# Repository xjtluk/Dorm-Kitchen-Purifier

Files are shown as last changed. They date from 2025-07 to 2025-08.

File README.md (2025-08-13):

# Smart Indoor Air Quality Monitor & Purifier

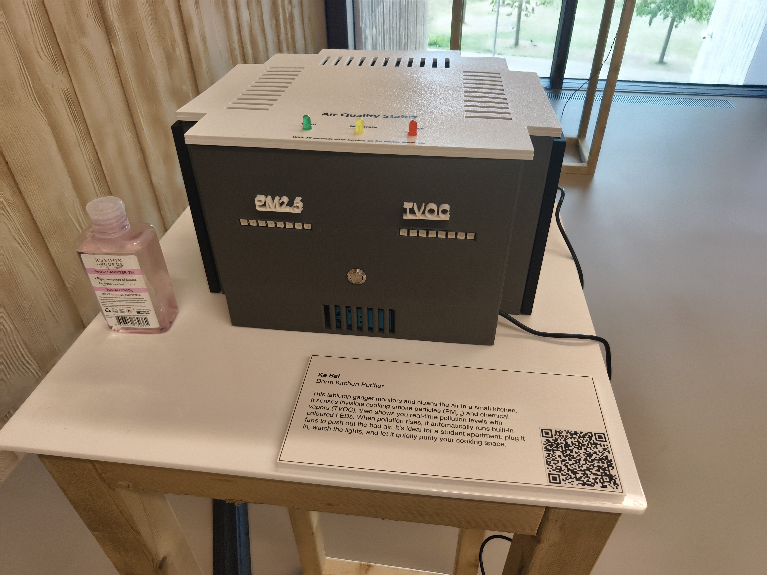
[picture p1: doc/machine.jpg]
机器图片

 
A comprehensive IoT-based air purification and monitoring system designed specifically for student residences, combining real-time pollution detection, automated purification control, and cloud data logging.






## 🌟 Features

- **Real-time Air Quality Monitoring**: Continuous measurement of PM₂.₅ and TVOC levels
- **Automated Purification Control**: Three-tier fan system with intelligent response scaling
- **Visual Feedback System**: Dual LED strips providing immediate air quality status
- **IoT Cloud Integration**: Automatic data logging to ThingSpeak platform
- **Compact Design**: Optimized for 12-15 m² student living spaces
- **Educational Focus**: Open-source design for learning and research

## 📊 Performance Results

### Purification Effectiveness
- **PM₂.₅ Reduction**: 31% reduction in peak concentrations
- **TVOC Reduction**: 13% reduction during active purification
- **Response Time**: System activation within 6 seconds of threshold violation

### System Specifications
- **Detection Range**: PM₂.₅ (0-1000 µg/m³), TVOC (0-60,000 ppb)
- **Sampling Rate**: 2-second intervals for real-time response
- **Clean Air Delivery Rate**: Up to 105 CFM with three-fan configuration
- **Operational Reliability**: 97.3% cloud upload success rate over 720+ hours

## 🔧 Hardware Components

### Core Components
- **Microcontroller**: ESP32 (dual-core, WiFi-enabled)
- **PM₂.₅ Sensor**: PMS5003 (Plantower) - laser-based optical sensing
- **TVOC Sensor**: SGP30 (Sensirion) - metal-oxide semiconductor
- **Purification**: 3x centrifugal fans with HEPA + activated carbon filtration
- **User Interface**: Dual 8-pixel NeoPixel LED strips, tactile control button

### Power & Control
- **Fan Control**: MOSFET-based switching (FQP30N06L N-channel)
- **Power Consumption**: 15W during active purification
- **Communication**: UART (PMS5003), I²C (SGP30), WiFi (cloud logging)

## 📦 Installation

### Hardware Setup
1. **3D Print Enclosure**: Use provided Fusion 360 files (3D model) for compact desktop unit
2. **Circuit Assembly**: Follow schematic for sensor and fan connections
3. **Filter Installation**: Insert HEPA + activated carbon cartridge

```
Pin Connections:
├── PMS5003: UART (pins 16/17)
├── SGP30: I²C (pins 21/22)
├── Fans: Digital control (pins 18/19)
├── NeoPixel LEDs: pins 25/26
└── Control Button: pin 4
```
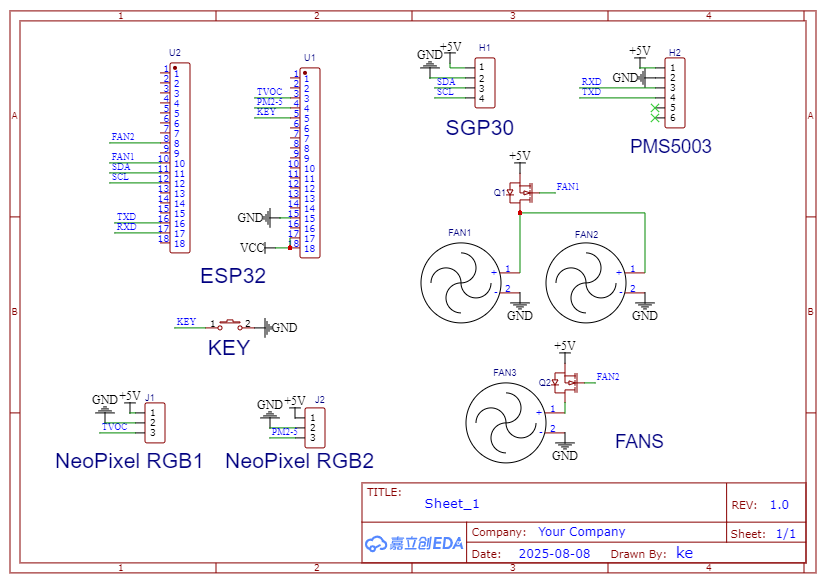
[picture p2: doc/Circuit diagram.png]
电路图片


### Software Setup
1. **Install Arduino IDE** with ESP32 board support
2. **Required Libraries**:
   ```
   - Adafruit_SGP30
   - Adafruit_PM25AQI
   - Adafruit_NeoPixel
   - WiFi (ESP32 built-in)
   - HTTPClient (ESP32 built-in)
   ```

3. **Configure WiFi & ThingSpeak**:
   ```cpp
   const char* ssid = "YOUR_WIFI_SSID";
   const char* password = "YOUR_WIFI_PASSWORD";
   const char* writeAPIKey = "YOUR_THINGSPEAK_API_KEY";
   ```

4. **Upload Code**: Flash `fyp.ino` to ESP32

## 🚀 Usage

### Basic Operation
1. **Power On**: Connect to 5V power supply
2. **Start System**: Press button to initiate 30-second boot sequence
3. **Monitor Status**: LED strips indicate air quality levels:
   - 🟢 **Green** (2 LEDs): Good air quality
   - 🟡 **Yellow** (4 LEDs): Moderate pollution
   - 🟠 **Orange** (4 LEDs): High pollution
   - 🔴 **Red** (8 LEDs): Extreme pollution

### Air Quality Thresholds
| Level | PM₂.₅ (µg/m³) | TVOC (ppb) | Fan Response |
|---|---|---|---|
| 0 | < 35 | < 300 | All fans OFF |
| 1 | 35-75 | 300-600 | 1 fan ON |
| 2 | 75-150 | 600-1000 | 2 fans ON |
| 3 | > 150 | > 1000 | 3 fans ON |

### Cloud Data Access
- Visit your ThingSpeak channel for real-time data visualization
- 15-second averaged data with automatic chart generation
- Historical trend analysis and export capabilities

## 📈 Data Analysis

The system logs comprehensive air quality data including:
- Time-series PM₂.₅ and TVOC measurements
- Fan activation events and duration
- Response effectiveness metrics
- Environmental correlation data

### Typical Pollution Sources Detected
- **Cooking Activities**: Stir-frying (peak: 275 µg/m³ PM₂.₅)
- **Personal Care**: Hand sanitizer (peak: 8,000 ppb TVOC)
- **Cleaning Products**: All-purpose cleaners (600-1200 ppb TVOC)

## 🛠 System Architecture

```
┌─────────────────┐    ┌─────────────────┐    ┌─────────────────┐
│   Sensor Data   │───▶│  Control Logic  │───▶│  User Interface │
│   Acquisition   │    │   & Response    │    │   & Feedback    │
└─────────────────┘    └─────────────────┘    └─────────────────┘
         │                       │                       │
         ▼                       ▼                       ▼
┌─────────────────┐    ┌─────────────────┐    ┌─────────────────┐
│  PMS5003 (PM)   │    │  Fan Control    │    │  LED Indicators │
│  SGP30 (TVOC)   │    │  (3-tier)       │    │  Status Display │
└─────────────────┘    └─────────────────┘    └─────────────────┘
                                │
                                ▼
                       ┌─────────────────┐
                       │  ThingSpeak     │
                       │  Cloud Logging  │
                       └─────────────────┘
```

## 🔬 Research Applications

This system has been validated for:
- **Environmental Health Research**: Quantifying indoor pollution exposure
- **Behavioral Studies**: Impact of real-time feedback on user actions
- **Engineering Education**: Hands-on IoT and environmental monitoring
- **Building Performance**: IAQ assessment in residential settings

### Validated Use Cases
- Student dormitory air quality management
- Cooking-related pollution control
- Educational laboratory modules
- Indoor environmental health studies

## 🤝 Contributing

This is an open-source educational project. Contributions welcome:

1. **Hardware Improvements**: Enhanced sensor integration, modular designs
2. **Software Features**: Advanced control algorithms, mobile app development
3. **Research Extensions**: Multi-institutional validation, health impact studies
4. **Documentation**: Setup guides, educational materials

## 📄 License

This project is released under an open-source license to support educational use and research collaboration. Please cite appropriately if used in academic work.

## 📚 Citation

If you use this system in research, please cite:
```
Smart Monitoring and Visualization of Indoor Air Quality in Student Residences
[Author Name], [Institution], [Year]
```

## 🔗 Related Resources

- [ThingSpeak Platform](https://thingspeak.com/) - IoT data logging service
- [ESP32 Documentation](https://docs.espressif.com/projects/esp-idf/en/latest/esp32/)
- [Indoor Air Quality Guidelines](https://www.who.int/news-room/fact-sheets/detail/ambient-(outdoor)-air-quality-and-health)

## 📞 Support

For technical questions or research collaboration:
- Create an issue in this repository
- Check the documentation in the `/docs` folder
- Review the troubleshooting guide in the user manual

---

**⚠️ Important**: This system is designed for educational and research purposes. While it provides meaningful air quality improvements, it should complement, not replace, proper ventilation and established safety practices.

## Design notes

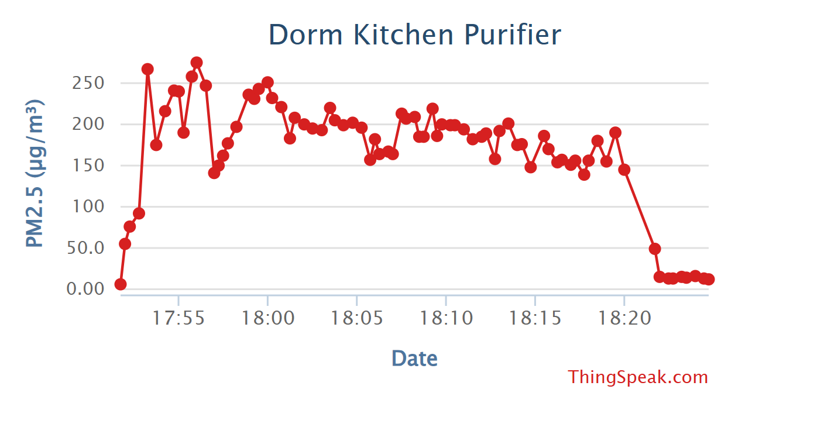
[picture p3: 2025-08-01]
doc/data3.png

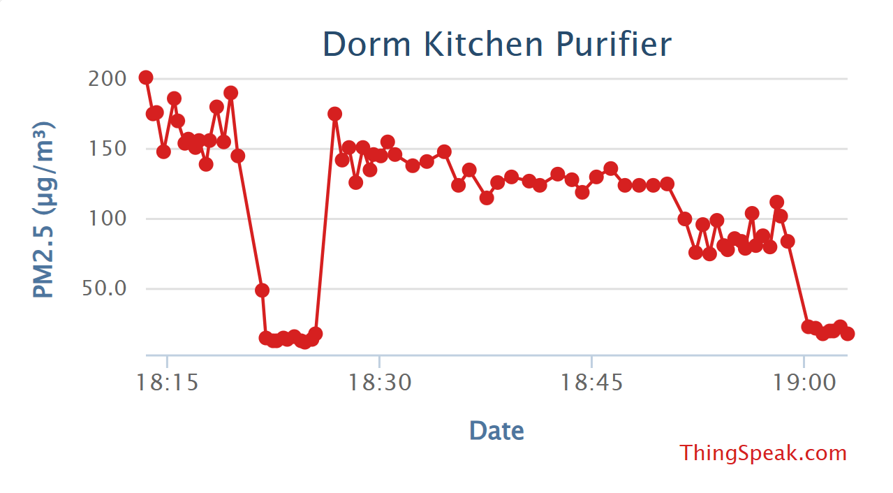
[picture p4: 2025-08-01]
doc/data4.png

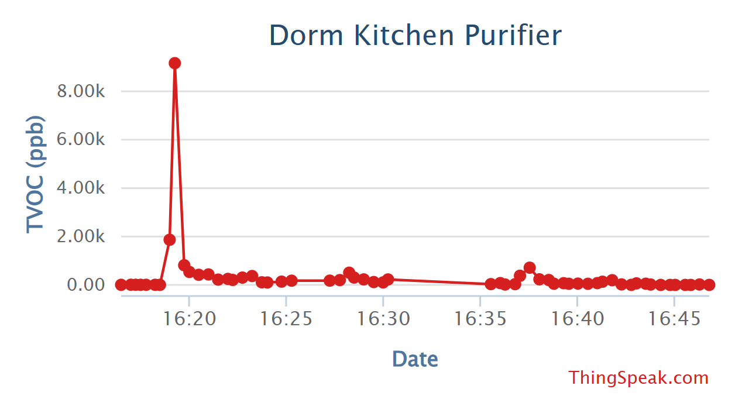
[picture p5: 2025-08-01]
doc/data6.png

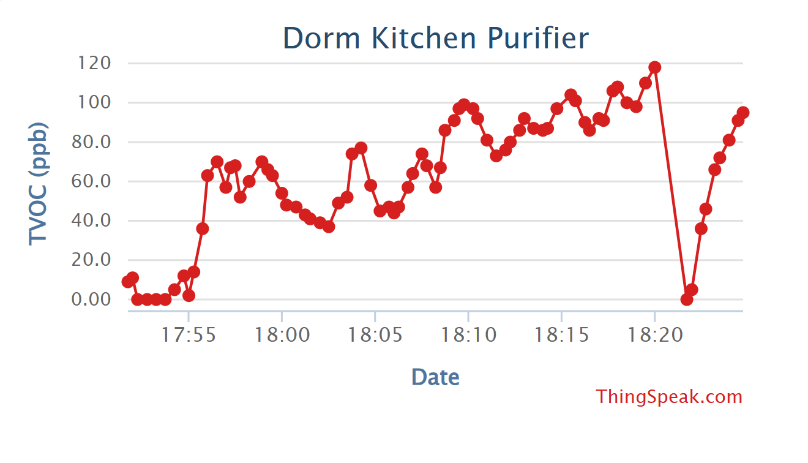
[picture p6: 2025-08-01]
doc/data1.png

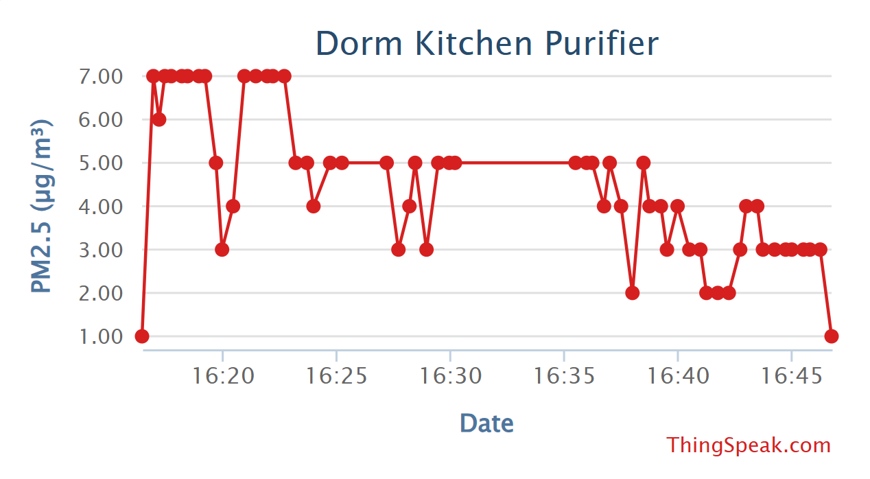
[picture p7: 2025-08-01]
doc/data5.png

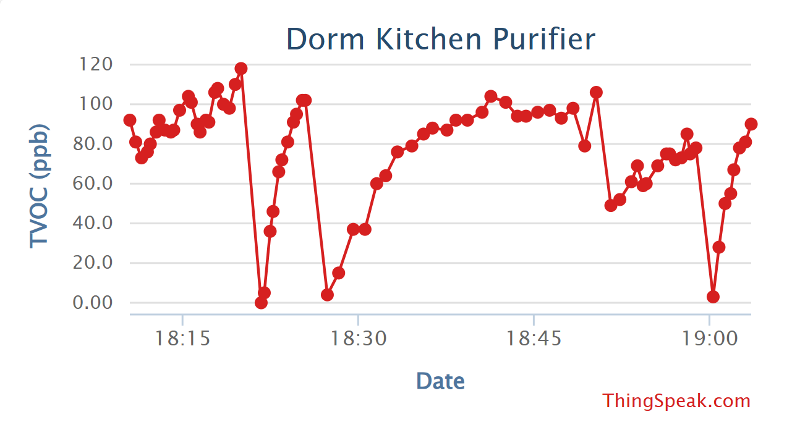
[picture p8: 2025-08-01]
doc/data2.png

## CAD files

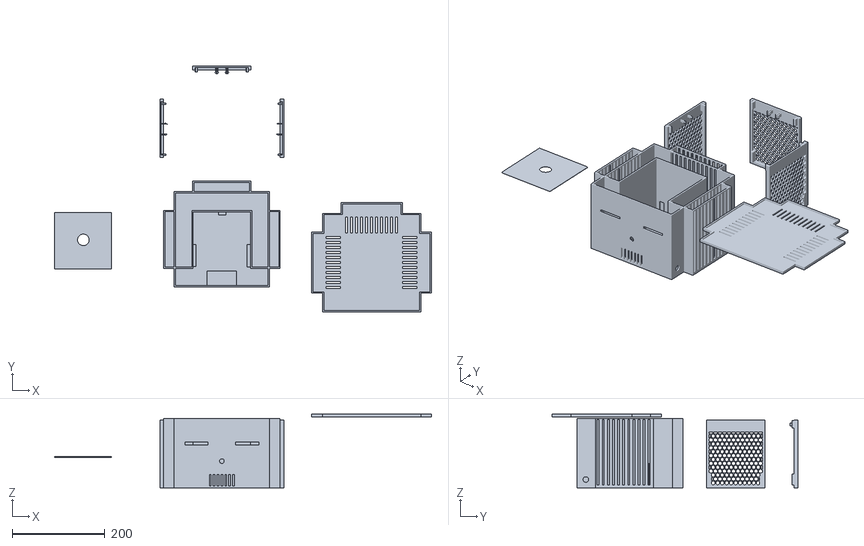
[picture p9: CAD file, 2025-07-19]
3D model/purifier.stl
814.0 x 530.2 x 159.0

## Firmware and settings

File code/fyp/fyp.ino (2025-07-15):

#include <Wire.h>
#include "Adafruit_SGP30.h"
#include "Adafruit_PM25AQI.h"
#include <Adafruit_NeoPixel.h>
#include <WiFi.h>
#include <HTTPClient.h>

// WiFi settings
const char* ssid            = "vivo50";
const char* password        = "bk666666";
const char* thingSpeakURL   = "http://api.thingspeak.com/update";
const char* writeAPIKey     = "HWLDOM7OUII2PRSC";

// Pin definitions
const int FAN_HIGH_PIN  = 18;
const int FAN_LOW_PIN   = 19;
const int BUTTON_PIN    = 4;
#define NEO_TVOC_PIN 25
#define NEO_PM25_PIN 26
#define NEO_COUNT    8

Adafruit_NeoPixel stripTVOC(NEO_COUNT, NEO_TVOC_PIN, NEO_GRB + NEO_KHZ800);
Adafruit_NeoPixel stripPM25(NEO_COUNT, NEO_PM25_PIN, NEO_GRB + NEO_KHZ800);

// Debounce parameters
int lastButtonStable  = HIGH, lastButtonReading = HIGH;
unsigned long lastDebounceTime = 0;
const unsigned long debounceDelay = 50;

// Sensor objects and thresholds
Adafruit_SGP30 sgp;
Adafruit_PM25AQI aqi;
uint16_t lastPM25 = 0;
int pm25FailCount = 0;
const int PM25_MAX_RETRIES = 5;
const uint16_t TVOC_LOW  = 300, TVOC_MED  = 600, TVOC_HIGH  = 1000;
const uint16_t PM25_LOW  = 35,  PM25_MED  = 75,  PM25_HIGH  = 150;

// Timing parameters
unsigned long lastMeasureTime = 0;
const unsigned long measureInterval = 2000;
unsigned long lastUploadTime  = 0;
const unsigned long uploadInterval = 15000;

// Accumulators for averaging
unsigned long tvocSum   = 0;
unsigned long pm25Sum   = 0;
unsigned int  sampleCount = 0;
uint16_t currentTVOC = 0;
uint16_t currentPM25 = 0;

// Boot animation parameters
const unsigned long totalPreheat  = 30000;
const int flashCycles             = 3;
const unsigned long flashInterval = 400;
const unsigned long flashTotal    = flashCycles * 3 * flashInterval;
const unsigned long stepInterval  = (totalPreheat - flashTotal) / NEO_COUNT;

enum State { OFF, BOOTING, RUNNING };
State state = OFF;
int preheatStepIndex          = 0;
unsigned long preheatLastTime = 0;
int flashCount                = 0;
bool flashOn                  = false;
unsigned long flashLastTime   = 0;

bool wifiConnected = false;

// Function prototypes
bool connectWiFi();
bool bootAnimation();
void handleButton();
void measureAndControl();
void uploadToThingSpeak(uint16_t avgTVOC, uint16_t avgPM25);
int calcAQLevel(uint16_t value, uint16_t low, uint16_t med, uint16_t high);
void updateLEDStrip(Adafruit_NeoPixel &strip, int level);

void setup() {
  Serial.begin(115200);
  while (!Serial) delay(10);
  Serial.println("=== Air Purifier Initialization ===");

  pinMode(BUTTON_PIN, INPUT_PULLUP);
  lastButtonReading = digitalRead(BUTTON_PIN);
  lastButtonStable  = lastButtonReading;

  pinMode(FAN_HIGH_PIN, OUTPUT);
  pinMode(FAN_LOW_PIN, OUTPUT);
  digitalWrite(FAN_HIGH_PIN, LOW);
  digitalWrite(FAN_LOW_PIN, LOW);

  stripTVOC.begin(); stripTVOC.setBrightness(50); stripTVOC.show();
  stripPM25.begin(); stripPM25.setBrightness(50); stripPM25.show();

  Wire.begin(21, 22);
  if (!sgp.begin()) { Serial.println("Error: SGP30 not detected"); while (1); }
  sgp.IAQinit();

  Serial2.begin(9600, SERIAL_8N1, 16, 17);
  if (!aqi.begin_UART(&Serial2)) { Serial.println("Error: PMS5003 not detected"); while (1); }

  Serial.println("Press button to start");
}

void loop() {
  handleButton();

  if (state == BOOTING) {
    if (bootAnimation()) {
      state = RUNNING;
      Serial.println("Boot complete, system running");
      lastMeasureTime = millis();
      tvocSum = pm25Sum = 0;
      sampleCount = 0;
      lastUploadTime = millis();
    }
  }
  else if (state == RUNNING) {
    unsigned long now = millis();
    if (now - lastMeasureTime >= measureInterval) {
      lastMeasureTime = now;
      measureAndControl();
      tvocSum   += currentTVOC;
      pm25Sum   += currentPM25;
      sampleCount++;
    }
    if (wifiConnected && now - lastUploadTime >= uploadInterval) {
      lastUploadTime = now;
      uint16_t avgTVOC = sampleCount ? tvocSum / sampleCount : currentTVOC;
      uint16_t avgPM25 = sampleCount ? pm25Sum / sampleCount : currentPM25;
      uploadToThingSpeak(avgTVOC, avgPM25);
      tvocSum = pm25Sum = 0;
      sampleCount = 0;
    }
  }
}

void handleButton() {
  int reading = digitalRead(BUTTON_PIN);
  if (reading != lastButtonReading) lastDebounceTime = millis();
  if (millis() - lastDebounceTime > debounceDelay) {
    if (reading != lastButtonStable) {
      lastButtonStable = reading;
      if (reading == LOW) {
        if (state == OFF) {
          Serial.println("Button pressed: starting boot sequence");
          state = BOOTING;
          preheatStepIndex  = 0;
          preheatLastTime   = millis();
          flashCount        = 0;
          flashOn           = false;
          wifiConnected     = connectWiFi();
        } else {
          Serial.println("Button pressed: shutting down");
          state = OFF;
          digitalWrite(FAN_HIGH_PIN, LOW);
          digitalWrite(FAN_LOW_PIN,  LOW);
          stripTVOC.clear(); stripTVOC.show();
          stripPM25.clear(); stripPM25.show();
        }
      }
    }
  }
  lastButtonReading = reading;
}

bool bootAnimation() {
  handleButton();
  unsigned long now = millis();
  if (preheatStepIndex < NEO_COUNT) {
    if (now - preheatLastTime >= stepInterval) {
      for (int i = 0; i < NEO_COUNT; i++) {
        uint32_t color = (i <= preheatStepIndex) ? stripTVOC.Color(0,0,255) : 0;
        stripTVOC.setPixelColor(i, color);
        stripPM25.setPixelColor(i, color);
      }
      stripTVOC.show(); stripPM25.show();
      preheatStepIndex++;
      preheatLastTime = now;
    }
    return false;
  } else if (flashCount < flashCycles*2) {
    if (now - flashLastTime >= flashInterval) {
      flashOn = !flashOn;
      for (int i = 0; i < NEO_COUNT; i++) {
        uint32_t color = flashOn ? stripTVOC.Color(0,0,255) : 0;
        stripTVOC.setPixelColor(i, color);
        stripPM25.setPixelColor(i, color);
      }
      stripTVOC.show(); stripPM25.show();
      flashCount++;
      flashLastTime = now;
    }
    return false;
  }
  stripTVOC.clear(); stripTVOC.show();
  stripPM25.clear(); stripPM25.show();
  return true;
}

void measureAndControl() {
  if (sgp.IAQmeasure()) currentTVOC = sgp.TVOC;
  PM25_AQI_Data d;
  if (aqi.read(&d)) {
    currentPM25 = d.pm25_standard;
    lastPM25    = currentPM25;
    pm25FailCount = 0;
  } else if (++pm25FailCount >= PM25_MAX_RETRIES) {
    Serial2.begin(9600, SERIAL_8N1, 16, 17);
    if (aqi.begin_UART(&Serial2)) pm25FailCount = 0;
  }
  Serial.printf("TVOC=%d ppb  PM2.5=%d µg/m³\n", currentTVOC, currentPM25);
  int lvlTV = calcAQLevel(currentTVOC, TVOC_LOW, TVOC_MED, TVOC_HIGH);
  int lvlPM = calcAQLevel(currentPM25, PM25_LOW, PM25_MED, PM25_HIGH);
  if (lvlTV>2||lvlPM>2)      digitalWrite(FAN_HIGH_PIN,HIGH),digitalWrite(FAN_LOW_PIN,HIGH);
  else if (lvlTV>1||lvlPM>1) digitalWrite(FAN_HIGH_PIN,HIGH),digitalWrite(FAN_LOW_PIN,LOW);
  else if (lvlTV>0||lvlPM>0) digitalWrite(FAN_HIGH_PIN,LOW), digitalWrite(FAN_LOW_PIN,HIGH);
  else                        digitalWrite(FAN_HIGH_PIN,LOW), digitalWrite(FAN_LOW_PIN,LOW);
  updateLEDStrip(stripTVOC, lvlTV);
  updateLEDStrip(stripPM25, lvlPM);
}

bool connectWiFi() {
  Serial.printf("Connecting to WiFi: %s\n", ssid);
  WiFi.begin(ssid, password);
  unsigned long start = millis();
  while (WiFi.status()!=WL_CONNECTED && millis()-start<5000) delay(100);
  if (WiFi.status()==WL_CONNECTED) {
    Serial.printf("Connected, IP: %s\n", WiFi.localIP().toString().c_str());
    return true;
  }
  Serial.println("WiFi connection failed, entering offline mode");
  return false;
}

void uploadToThingSpeak(uint16_t avgTVOC, uint16_t avgPM25) {
  if (!wifiConnected) return;
  HTTPClient http;
  http.begin(thingSpeakURL);
  http.addHeader("Content-Type","application/x-www-form-urlencoded");
  String payload = "api_key="+String(writeAPIKey)
                   +"&field1="+String(avgTVOC)
                   +"&field2="+String(avgPM25);
  int code = http.POST(payload);
  if (code>0) Serial.printf("Upload OK, HTTP code: %d\n", code);
  else       Serial.printf("Upload failed, code: %d\n", code);
  http.end();
}

int calcAQLevel(uint16_t v,uint16_t low,uint16_t med,uint16_t high) {
  if (v>=high) return 3;
  if (v>=med)  return 2;
  if (v>=low)  return 1;
  return 0;
}

void updateLEDStrip(Adafruit_NeoPixel &strip,int level) {
  int cnt; uint32_t col;
  switch(level) {
    case 0: cnt=2; col=strip.Color(0,255,0); break;
    case 1: cnt=4; col=strip.Color(255,255,0); break;
    case 2: cnt=4; col=strip.Color(255,165,0); break;
    default:cnt=8; col=strip.Color(255,0,0);   break;
  }
  for(int i=0;i<NEO_COUNT;i++) strip.setPixelColor(i, i<cnt?col:0);
  strip.show();
}

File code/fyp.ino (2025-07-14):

#include <Wire.h>
#include "Adafruit_SGP30.h"
#include "Adafruit_PM25AQI.h"
#include <Adafruit_NeoPixel.h>

// —— 引脚定义 —— 
const int FAN12_PIN    = 18;
const int FAN3_PIN     = 19;
const int BUTTON_PIN   = 4;

#define NEO_TVOC_PIN    25
#define NEO_PM25_PIN    26
#define NEO_COUNT       8

// —— NeoPixel 实例 —— 
Adafruit_NeoPixel stripTVOC(NEO_COUNT, NEO_TVOC_PIN, NEO_GRB + NEO_KHZ800);
Adafruit_NeoPixel stripPM25(NEO_COUNT, NEO_PM25_PIN, NEO_GRB + NEO_KHZ800);

// —— 按键去抖 —— 
int  lastButtonStable   = HIGH, lastButtonReading = HIGH;
unsigned long lastDebounceTime = 0;
const unsigned long debounceDelay = 50;

// —— 传感器与阈值 —— 
Adafruit_SGP30 sgp;
Adafruit_PM25AQI aqi;
uint16_t lastPM25 = 0;
int pm25FailCount = 0;
const int PM25_MAX_RETRIES = 5;

const uint16_t TVOC_LOW  = 300, TVOC_MED  = 600, TVOC_HIGH  = 1000;
const uint16_t PM25_LOW  = 35,  PM25_MED  = 75,  PM25_HIGH  = 150;

// —— 测量定时 —— 
unsigned long lastMeasureTime = 0;
const unsigned long measureInterval = 2000;

// —— 预热设置 —— 
const unsigned long totalPreheat  = 30000;    // 30s
const int flashCycles             = 3;
const unsigned long flashInterval = 400;
const unsigned long flashTotal    = flashCycles * 3 * flashInterval;
const unsigned long stepInterval  = (totalPreheat - flashTotal) / NEO_COUNT;

// —— 状态机 —— 
enum State { OFF, PREHEAT, RUNNING };
State state = OFF;

// —— PREHEAT 子状态 —— 
int preheatStepIndex    = 0;
unsigned long preheatLastTime = 0;
int flashCount          = 0;
bool flashOn            = false;
unsigned long flashLastTime = 0;

void setup() {
  Serial.begin(115200);
  while (!Serial) delay(10);
  Serial.println("\n=== 智能净化器初始化 ===");

  // 按键
  pinMode(BUTTON_PIN, INPUT_PULLUP);
  lastButtonReading = digitalRead(BUTTON_PIN);
  lastButtonStable  = lastButtonReading;

  // 风扇
  pinMode(FAN12_PIN, OUTPUT);
  pinMode(FAN3_PIN,  OUTPUT);
  digitalWrite(FAN12_PIN, LOW);
  digitalWrite(FAN3_PIN,  LOW);

  // LED
  stripTVOC.begin(); stripTVOC.show();
  stripPM25.begin(); stripPM25.show();

  // SGP30 (I²C)
  Wire.begin(21, 22);
  if (!sgp.begin()) {
    Serial.println("SGP30 未连接");
    while (1);
  }
  sgp.IAQinit();
  Serial.println("SGP30 已就绪");

  // PMS5003 (UART)
  Serial2.begin(9600, SERIAL_8N1, 16, 17);
  if (!aqi.begin_UART(&Serial2)) {
    Serial.println("PMS5003 未连接");
    while (1);
  }
  Serial.println("PMS5003 已就绪");

  Serial.println("请按按钮开机");
}

void loop() {
  handleButton();

  if (state == PREHEAT) {
    if (preheatStep()) {
      state = RUNNING;
      Serial.println("\n预热完成，进入运行");
      lastMeasureTime = millis();
    }
  }
  else if (state == RUNNING) {
    if (millis() - lastMeasureTime >= measureInterval) {
      lastMeasureTime = millis();
      measureAndControl();
    }
  }
}

void handleButton() {
  int r = digitalRead(BUTTON_PIN);
  if (r != lastButtonReading) lastDebounceTime = millis();
  if (millis() - lastDebounceTime > debounceDelay) {
    if (r != lastButtonStable) {
      lastButtonStable = r;
      if (r == LOW) {
        if (state == OFF) {
          state = PREHEAT;
          Serial.println("\n按钮：开机，开始预热");
          preheatStepIndex = 0;
          preheatLastTime  = millis();
          flashCount       = 0;
          flashOn          = false;
        }
        else if (state == RUNNING) {
          state = OFF;
          Serial.println("\n按钮：关机");
          digitalWrite(FAN12_PIN, LOW);
          digitalWrite(FAN3_PIN,  LOW);
          stripTVOC.clear(); stripTVOC.show();
          stripPM25.clear(); stripPM25.show();
        }
      }
    }
  }
  lastButtonReading = r;
}

// 返回 true 当 PREHEAT 完成
bool preheatStep() {
  unsigned long now = millis();

  if (preheatStepIndex < NEO_COUNT) {
    if (now - preheatLastTime >= stepInterval) {
      for (int i = 0; i < NEO_COUNT; i++) {
        uint32_t c = (i <= preheatStepIndex) ? stripTVOC.Color(0, 0, 255) : 0;
        stripTVOC.setPixelColor(i, c);
        stripPM25.setPixelColor(i, c);
      }
      stripTVOC.show(); stripPM25.show();
      preheatStepIndex++;
      preheatLastTime = now;
    }
    return false;
  }
  else if (flashCount < flashCycles * 2) {
    if (now - flashLastTime >= flashInterval) {
      flashOn = !flashOn;
      for (int i = 0; i < NEO_COUNT; i++) {
        uint32_t c = flashOn ? stripTVOC.Color(0, 0, 255) : 0;
        stripTVOC.setPixelColor(i, c);
        stripPM25.setPixelColor(i, c);
      }
      stripTVOC.show(); stripPM25.show();
      flashCount++;
      flashLastTime = now;
    }
    return false;
  }
  else {
    stripTVOC.clear(); stripTVOC.show();
    stripPM25.clear(); stripPM25.show();
    return true;
  }
}

void measureAndControl() {
  // 读取 TVOC
  uint16_t tvoc = UINT16_MAX;
  if (sgp.IAQmeasure()) {
    tvoc = sgp.TVOC;
  } else {
    Serial.println("Error: TVOC 读取失败");
  }

  // 读取 PM2.5（使用缓存避免误判）
  uint16_t pm25 = lastPM25;
  PM25_AQI_Data d;
  if (aqi.read(&d)) {
    pm25 = d.pm25_standard;
    lastPM25 = pm25;
    pm25FailCount = 0;
  } else {
    pm25FailCount++;
    Serial.printf("Warning: PM2.5 读取失败 (%d)\n", pm25FailCount);
    if (pm25FailCount >= PM25_MAX_RETRIES) {
      Serial.println("-> 重新初始化 PMS5003 …");
      Serial2.begin(9600, SERIAL_8N1, 16, 17);
      if (aqi.begin_UART(&Serial2)) {
        Serial.println("   PMS5003 重连成功");
        pm25FailCount = 0;
      } else {
        Serial.println("   PMS5003 重连失败");
      }
    }
  }

  Serial.printf("TVOC=%d ppb  PM2.5=%d µg/m³  ", tvoc, pm25);

  // 计算等级
  int lTV = calcLevel(tvoc, TVOC_LOW, TVOC_MED, TVOC_HIGH);
  int lP  = calcLevel(pm25, PM25_LOW, PM25_MED, PM25_HIGH);

  bool hiP  = (lTV > 2) || (lP > 2);
  bool medP = (lTV > 1) || (lP > 1);
  bool lowP = (lTV > 0) || (lP > 0);

  if (hiP) {
    digitalWrite(FAN12_PIN, HIGH);
    digitalWrite(FAN3_PIN,  HIGH);
    Serial.println("等级：严重");
  } else if (medP) {
    digitalWrite(FAN12_PIN, HIGH);
    digitalWrite(FAN3_PIN,  LOW);
    Serial.println("等级：中等");
  } else if (lowP) {
    digitalWrite(FAN12_PIN, LOW);
    digitalWrite(FAN3_PIN,  HIGH);
    Serial.println("等级：初等");
  } else {
    digitalWrite(FAN12_PIN, LOW);
    digitalWrite(FAN3_PIN,  LOW);
    Serial.println("等级：正常");
  }

  updateStripLevel(stripTVOC, lTV);
  updateStripLevel(stripPM25, lP);
}

int calcLevel(uint16_t v, uint16_t lw, uint16_t mw, uint16_t hw) {
  if (v >= hw) return 3;
  if (v >= mw) return 2;
  if (v >= lw) return 1;
  return 0;
}

void updateStripLevel(Adafruit_NeoPixel &s, int level) {
  int cnt; uint32_t col;
  switch (level) {
    case 0: cnt = 2; col = s.Color(0, 255, 0);   break;
    case 1: cnt = 4; col = s.Color(255, 255, 0); break;
    case 2: cnt = 4; col = s.Color(255, 165, 0); break;
    default:cnt = 8; col = s.Color(255,   0, 0); break;
  }
  for (int i = 0; i < NEO_COUNT; i++) {
    s.setPixelColor(i, i < cnt ? col : 0);
  }
  s.show();
}

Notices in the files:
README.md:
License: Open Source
